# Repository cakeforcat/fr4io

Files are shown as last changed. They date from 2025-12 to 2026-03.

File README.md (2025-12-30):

# FR4io
This is an attempt at creating a modular set of tiles that can create movement systems from factorio in real life.
## Proposed features
 - smart, addressable tiles
 - fully reconfigurable
 - hot-swappable
 - extendable (arms, splitters, combiners)
 - magnetically actuated
 - low-cost-ish

## magnetic actuation
each tile will consist of 5 PCB coils that can be thought of as a very crude linear motor. Payload to be moved are purely for aesthetics and will be as light as possible.
The tile will be able to sense the presense of a payload by measuring the current on each coil through a shunt resistor.

## network
tiles connect to each other through a simple UART link. Each powered on tile announces it's presence on all 4 edges abd nearby tiles respond with acknowledges. The entire graph is built and maintained by the central controller. The firmware on each tile is meant to be as minimal as possible to allow for OTW (Over the Wire) updates. All higher level functions are to be implemented on the controller. Each tile is addressable.

## EMF
will hopefully be presented at EMF2026? will depend on tickets and if we actually make it :D

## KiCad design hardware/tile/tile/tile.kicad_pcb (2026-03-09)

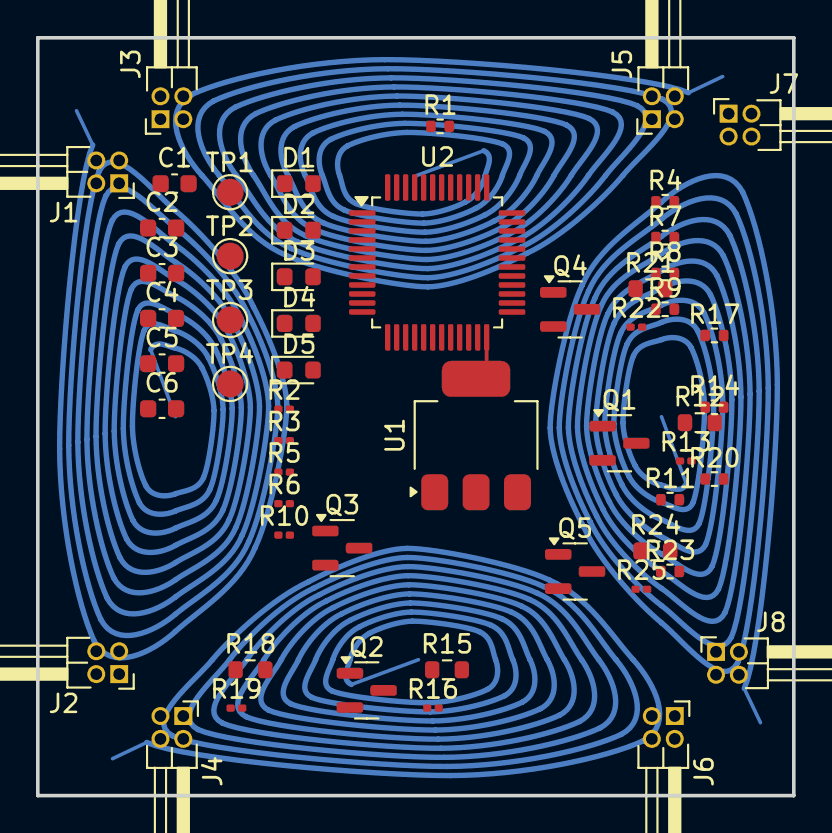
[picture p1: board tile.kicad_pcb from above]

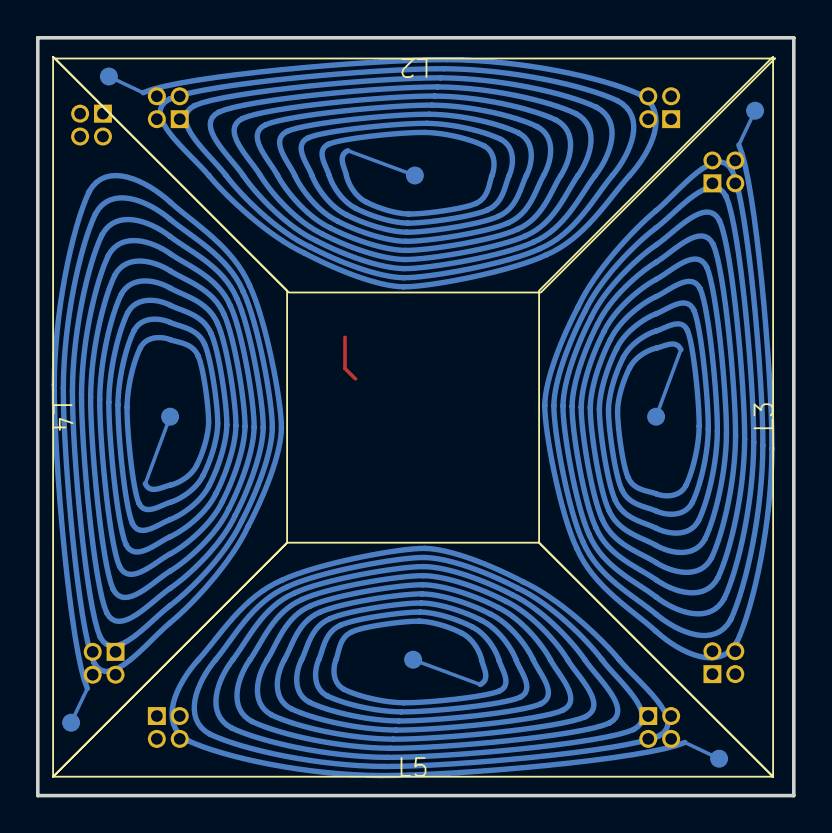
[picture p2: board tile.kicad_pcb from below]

Board: 4 copper layers, 42.0 x 42.1 mm, 59 parts (4 on the bottom side), 46 nets.

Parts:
C1, C3: 10uF; C_0603_1608Metric
C2, C4: 100nF; C_0603_1608Metric
C5, C6: 0.1uF; C_0603_1608Metric
D1, D2, D3, D4, D5: LED; LED_0603_1608Metric
J1, J2, J3, J4, J5, J6, J7, J8: Conn_02x02_Counter_Clockwise; PinHeader_2x02_P1.27mm_Horizontal
L2, L3, L4, L5: L; coil_done
Q1, Q2, Q3, Q4, Q5: AO3400A; SOT-23
R1, R4, R9: 10K; R_0402_1005Metric
R2, R3, R5, R6, R10: 330R; R_0201_0603Metric
R7: 220K; R_0402_1005Metric
R8: 100K; R_0402_1005Metric
R11, R14, R17, R20, R23: 10R; R_0402_1005Metric
R12, R15, R18, R21, R24: 10K; R_0603_1608Metric
R13, R16, R19, R22, R25: 1R; R_0201_0603Metric
TP1, TP2, TP3, TP4: PROG; TestPoint_Pad_D1.5mm
U1: AMS1117-3.3; SOT-223-3_TabPin2
U2: CH32V203C8T6; LQFP-48_7x7mm_P0.5mm

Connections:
+3V3: C3.1, C4.1, C5.1, C6.1, R2.1, R4.2, R9.2, TP3.1, U1.2 (VO), U2.1 (VBAT), U2.9 (VDDA), U2.24 (VDD_VIO), U2.36 (VDD), U2.48 (VDD)
+9V: C1.1, C2.1, J1.1, J2.2, J3.4, J4.1, J5.3, J6.2, J7.4, J8.3, L2.1, L3.1, L4.1, L5.1, R7.2, U1.3 (VI)
/ADC_IN0: R13.1, U2.10 (PA0)
/ADC_IN1: L2.2, R16.1, U2.11 (PA1)
/ADC_IN4: L3.2, R19.1, U2.14 (PA4)
/ADC_IN5: L4.2, R22.1, U2.15 (PA5)
/ADC_IN6: L5.2, R25.1, U2.16 (PA6)
/ADC_IN7: R7.1, R8.2, U2.17 (PA7)
/BOOT0: R4.1, U2.44 (BOOT0)
/BOOT1: R1.2, U2.20 (PB2)
/COIL1: R11.1, U2.39 (PB3)
/COIL2: R14.1, U2.40 (PB4)
/COIL3: R17.1, U2.41 (PB5)
/COIL4: R20.1, U2.42 (PB6)
/COIL5: R23.1, U2.43 (PB7)
/LED1: R3.1, U2.25 (PB12)
/LED2: R5.1, U2.26 (PB13)
/LED3: R6.1, U2.27 (PB14)
/LED4: R10.1, U2.28 (PB15)
/NRST: R9.1, U2.7 (~RST)
/SWCLK: TP2.1, U2.37 (SWCLK)
/SWDIO: TP1.1, U2.34 (SWDIO)
/USART1_RX: J2.3, J2.4, U2.31 (PA10)
/USART1_TX: J1.3, J1.4, U2.30 (PA9)
/USART2_RX: J7.1, J7.2, U2.13 (PA3)
/USART2_TX: J8.1, J8.2, U2.12 (PA2)
/USART3_RX: J6.3, J6.4, U2.22 (PB11)
/USART3_TX: J4.3, J4.4, U2.21 (PB10)
/USART4_RX: J3.1, J3.2, U2.19 (PB1)
/USART4_TX: J5.1, J5.2, U2.18 (PB0)
GND: C1.2, C2.2, C3.2, C4.2, C5.2, C6.2, D1.1 (K), D2.1 (K), D3.1 (K), D4.1 (K), D5.1 (K), J1.2, J2.1, J3.3, J4.2, J5.4, J6.1, J7.3, J8.4, Q1.2 (S), Q2.2 (S), Q3.2 (S), Q4.2 (S), Q5.2 (S), R1.1, R8.1, R12.2, R15.2, R18.2, R21.2, R24.2, TP4.1, U1.1 (GND), U2.8 (VSSA), U2.23 (VSS), U2.35 (VSS), U2.47 (VSS)
unnamed: D1.2 (A), R2.2
unnamed: D2.2 (A), R3.2
unnamed: D3.2 (A), R5.2
unnamed: D4.2 (A), R6.2
unnamed: D5.2 (A), R10.2
unnamed: Q1.3 (D), R13.2
unnamed: Q1.1 (G), R11.2, R12.1
unnamed: Q2.3 (D), R16.2
unnamed: Q2.1 (G), R14.2, R15.1
unnamed: Q3.3 (D), R19.2
unnamed: Q3.1 (G), R17.2, R18.1
unnamed: Q4.3 (D), R22.2
unnamed: Q4.1 (G), R20.2, R21.1
unnamed: Q5.3 (D), R25.2
unnamed: Q5.1 (G), R23.2, R24.1

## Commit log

2025-12-30 add tile kicad project
    [tile.kicad_pcb, tile.kicad_sch]
2025-12-31 init schematic for tile
    [tile.kicad_sch]
2026-01-03 tile schematic v1
    [coil.kicad_sch, connectors.kicad_sch, tile.kicad_sch]
2026-01-04 add debug, make tile schematic pretty
    [connectors.kicad_sch, tile.kicad_sch]
2026-01-04 add vin sense to tile
    [tile.kicad_sch]
2026-01-04 fix tile sense resistors
    [tile.kicad_sch]
2026-03-09 added coils will improve them later
    [coil_center.kicad_sch, connectors.kicad_sch, tile.kicad_pcb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]
